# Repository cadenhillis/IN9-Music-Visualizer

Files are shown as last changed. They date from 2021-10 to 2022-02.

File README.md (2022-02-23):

# IN9-Music-Visualizer
Teensy 3.6  Based Music Visualizer utilizing the built-in audio library

11 IN9 Nixie tubes are driven thru low side BJT current sinks. Controllable thru the Teensy's PWM and powerful Audio Library.

The 12-150V boost supply is no laughing matter, by far the hardest to design -- as 11 IN9's can draw a peak of 20W. The medium power and high-voltage are quite a challenge for any electronics hobbiest.



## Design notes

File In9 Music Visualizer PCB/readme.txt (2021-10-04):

This top level KiCad project is the top-level schematic with the board.

The Power Board and Signal Board sub directorys are boards separated by their sections, as the power side works better with 2oz 4 layers and the signal side only needs 2 layers and 2oz is overkill

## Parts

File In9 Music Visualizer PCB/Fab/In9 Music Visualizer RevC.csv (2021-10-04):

Source: | E:\Projects\4.4 IN9 Music Visualizer RevC\In9 Music Visualizer RevC\In9 Music Visualizer RevC.sch
Date: | 8/29/2021 4:59:00 PM
Tool: | Eeschema (5.1.9)-1
Generator: | C:\Program Files\KiCad\bin\scripting\plugins/bom_csv_grouped_by_value.py
Component Count: | 98
Individual Components:
Item | Qty | Reference(s) | Value | LibPart | Footprint | Datasheet
 |  | C1 | 0.1uF | Device:C | Capacitor_SMD:C_0805_2012Metric_Pad1.18x1.45mm_HandSolder | 08055C104KAT4A
 |  | C2 | 620pF | Device:C | Capacitor_SMD:C_0805_2012Metric_Pad1.18x1.45mm_HandSolder | CC0805JRNPO9BN621
 |  | C3 | 0.1uF | Device:C | Capacitor_SMD:C_0805_2012Metric_Pad1.18x1.45mm_HandSolder | 08055C104KAT4A
 |  | C4 | 0.1uF | Device:C | Capacitor_SMD:C_0805_2012Metric_Pad1.18x1.45mm_HandSolder | 08055C104KAT4A
 |  | C5 | 100uF | Device:CP1 | Capacitor_THT:CP_Radial_D6.3mm_P2.50mm | ESY107M025AE3AA
 |  | C6 | 10uF | Device:C | Capacitor_SMD:C_0805_2012Metric_Pad1.18x1.45mm_HandSolder | GRM21BR61E106MA73L
 |  | C7 | 10uF | Device:C | Capacitor_SMD:C_0805_2012Metric_Pad1.18x1.45mm_HandSolder | GRM21BR61E106MA73L
 |  | C8 | 82uF | Device:CP1 | Capacitor_THT:CP_Radial_D18.0mm_P7.50mm | EEU-ED2E820S
 |  | C9 | 82uF | Device:CP1 | Capacitor_THT:CP_Radial_D18.0mm_P7.50mm | EEU-ED2E820S
 |  | C10 | 1uF | Device:C | Capacitor_SMD:C_2220_5650Metric_Pad1.97x5.40mm_HandSolder | C5750X7R2E105K230KA
 |  | C11 | 1uF | Device:C | Capacitor_SMD:C_2220_5650Metric_Pad1.97x5.40mm_HandSolder | C5750X7R2E105K230KA
 |  | C12 | 1uF | Device:C | Capacitor_SMD:C_2220_5650Metric_Pad1.97x5.40mm_HandSolder | C5750X7R2E105K230KA
 |  | C13 | 1uF | Device:C | Capacitor_SMD:C_2220_5650Metric_Pad1.97x5.40mm_HandSolder | C5750X7R2E105K230KA
 |  | C14 | 0.1uF | Device:C | Capacitor_SMD:C_0805_2012Metric_Pad1.18x1.45mm_HandSolder | 08055C104KAT4A
 |  | C15 | 0.16uF | Device:C | Capacitor_SMD:C_0805_2012Metric_Pad1.18x1.45mm_HandSolder | CL21B154KBFNNNG
 |  | C16 | 3.3nF | Device:C | Capacitor_SMD:C_0805_2012Metric_Pad1.18x1.45mm_HandSolder | 885012207119
 |  | C17 | 10nF | Device:C | Capacitor_SMD:C_0805_2012Metric_Pad1.18x1.45mm_HandSolder | 08055C103KAT2A
 |  | C18 | 0.1uF | Device:C | Capacitor_SMD:C_0805_2012Metric_Pad1.18x1.45mm_HandSolder | 08055C104KAT4A
 |  | C19 | 10uF | Device:C | Capacitor_SMD:C_0805_2012Metric_Pad1.18x1.45mm_HandSolder | GRM21BR61E106MA73L
 |  | C20 | 10uF | Device:C | Capacitor_SMD:C_0805_2012Metric_Pad1.18x1.45mm_HandSolder | GRM21BR61E106MA73L
 |  | C21 | 0.1uF | Device:C | Capacitor_SMD:C_0805_2012Metric_Pad1.18x1.45mm_HandSolder | 08055C104KAT4A
 |  | C22 | 22pF | Device:C | Capacitor_SMD:C_0805_2012Metric_Pad1.18x1.45mm_HandSolder | CL21C220JBANNNC
 |  | C23 | 22uF | Device:C | Capacitor_SMD:C_0805_2012Metric_Pad1.18x1.45mm_HandSolder | CL21A226MOCLRNC
 |  | C24 | 22uF | Device:C | Capacitor_SMD:C_0805_2012Metric_Pad1.18x1.45mm_HandSolder | CL21A226MOCLRNC
 |  | C25 | 4.7uF | Device:C | Capacitor_SMD:C_0805_2012Metric_Pad1.18x1.45mm_HandSolder | CL21A475KPFNNNE
 |  | C26 | 4.7uF | Device:C | Capacitor_SMD:C_0805_2012Metric_Pad1.18x1.45mm_HandSolder | CL21A475KPFNNNE
 |  | C27 | 4.7uF | Device:C | Capacitor_SMD:C_0805_2012Metric_Pad1.18x1.45mm_HandSolder | CL21A475KPFNNNE
 |  | C28 | 4.7uF | Device:C | Capacitor_SMD:C_0805_2012Metric_Pad1.18x1.45mm_HandSolder | CL21A475KPFNNNE
 |  | C29 | 4.7uF | Device:C | Capacitor_SMD:C_0805_2012Metric_Pad1.18x1.45mm_HandSolder | CL21A475KPFNNNE
 |  | C30 | 4.7uF | Device:C | Capacitor_SMD:C_0805_2012Metric_Pad1.18x1.45mm_HandSolder | CL21A475KPFNNNE
 |  | C31 | 4.7uF | Device:C | Capacitor_SMD:C_0805_2012Metric_Pad1.18x1.45mm_HandSolder | CL21A475KPFNNNE
 |  | C32 | 4.7uF | Device:C | Capacitor_SMD:C_0805_2012Metric_Pad1.18x1.45mm_HandSolder | CL21A475KPFNNNE
 |  | C33 | 4.7uF | Device:C | Capacitor_SMD:C_0805_2012Metric_Pad1.18x1.45mm_HandSolder | CL21A475KPFNNNE
 |  | C34 | 4.7uF | Device:C | Capacitor_SMD:C_0805_2012Metric_Pad1.18x1.45mm_HandSolder | CL21A475KPFNNNE
 |  | C35 | 4.7uF | Device:C | Capacitor_SMD:C_0805_2012Metric_Pad1.18x1.45mm_HandSolder | CL21A475KPFNNNE
 |  | D1 | MUR860J | Device:D | Diode_SMD:D_SMC_Handsoldering | MUR860J
 |  | HS1 | V6560W | Mechanical:Heatsink | My_Library:V6560W | V6560W
 |  | J1 | PWR_IN | Connector_Generic:Conn_01x02 | My_Library:640456-2 | 640456-2
 |  | J2 | PWR_IN | Connector_Generic:Conn_01x02 | My_Library:640456-2 | 640456-2
 |  | J3 | MIC_INPUT | Connector_Generic:Conn_01x03 | My_Library:640456-3 | 640456-3
 |  | J4 | IN9_MOUNTING_BOARD | Connector_Generic:Conn_01x12 | Connector_PinHeader_2.54mm:PinHeader_2x06_P2.54mm_Vertical | BHR-12-VUA
 |  | L1 | 330uH | Device:L | My_Library:L_Murata_6000B | 60B334C
 |  | L2 | 4.7uH | Device:L | Inductor_SMD:L_Bourns_SRN6045TA | SRN6045-4R7Y
 |  | MCU1 | Teensy 3.6 | Connector_Generic:Conn_02x24_Counter_Clockwise | My_Library:Teensy3.6 | ~
 |  | Q1 | DMN6140L-13 | Device:Q_NMOS_GSD | Package_TO_SOT_SMD:SOT-23_Handsoldering | DMN6140L-13
 |  | Q2 | STF13NM60N | Device:Q_NMOS_GDS | Package_TO_SOT_THT:TO-220-3_Vertical | STF13NM60N
 |  | Q3 | FZT857TA | Device:Q_NPN_BCE | Package_TO_SOT_SMD:SOT-223-3_TabPin2 | FZT857TA
 |  | Q4 | FZT857TA | Device:Q_NPN_BCE | Package_TO_SOT_SMD:SOT-223-3_TabPin2 | FZT857TA
 |  | Q5 | FZT857TA | Device:Q_NPN_BCE | Package_TO_SOT_SMD:SOT-223-3_TabPin2 | FZT857TA
 |  | Q6 | FZT857TA | Device:Q_NPN_BCE | Package_TO_SOT_SMD:SOT-223-3_TabPin2 | FZT857TA
 |  | Q7 | FZT857TA | Device:Q_NPN_BCE | Package_TO_SOT_SMD:SOT-223-3_TabPin2 | FZT857TA
 |  | Q8 | FZT857TA | Device:Q_NPN_BCE | Package_TO_SOT_SMD:SOT-223-3_TabPin2 | FZT857TA
 |  | Q9 | FZT857TA | Device:Q_NPN_BCE | Package_TO_SOT_SMD:SOT-223-3_TabPin2 | FZT857TA
 |  | Q10 | FZT857TA | Device:Q_NPN_BCE | Package_TO_SOT_SMD:SOT-223-3_TabPin2 | FZT857TA
 |  | Q11 | FZT857TA | Device:Q_NPN_BCE | Package_TO_SOT_SMD:SOT-223-3_TabPin2 | FZT857TA
 |  | Q12 | FZT857TA | Device:Q_NPN_BCE | Package_TO_SOT_SMD:SOT-223-3_TabPin2 | FZT857TA
 |  | Q13 | FZT857TA | Device:Q_NPN_BCE | Package_TO_SOT_SMD:SOT-223-3_TabPin2 | FZT857TA
 |  | R1 | 10k | Device:R_US | Resistor_SMD:R_0805_2012Metric_Pad1.20x1.40mm_HandSolder | RNCP0805FTD10K0
 |  | R2 | 69.8k | Device:R_US | Resistor_SMD:R_0805_2012Metric_Pad1.20x1.40mm_HandSolder | RC0805FR-0769K8L
 |  | R3 | 330 | Device:R_US | Resistor_SMD:R_0805_2012Metric_Pad1.20x1.40mm_HandSolder | CRGCQ0805F330R
 |  | R4 | 20k | Device:R_US | Resistor_SMD:R_0805_2012Metric_Pad1.20x1.40mm_HandSolder | CRG0805F20K
 |  | R5 | 10k | Device:R_US | Resistor_SMD:R_0805_2012Metric_Pad1.20x1.40mm_HandSolder | RNCP0805FTD10K0
 |  | R6 | 10k | Device:R_US | Resistor_SMD:R_0805_2012Metric_Pad1.20x1.40mm_HandSolder | RNCP0805FTD10K0
 |  | R7 | 20 | Device:R_US | Resistor_SMD:R_0805_2012Metric_Pad1.20x1.40mm_HandSolder | RNCP0805FTD20R0
 |  | R8 | 180k | Device:R_US | Resistor_SMD:R_0805_2012Metric_Pad1.20x1.40mm_HandSolder | RMCF0805FT180K
 |  | R9 | 1M | Device:R_US | Resistor_SMD:R_0805_2012Metric_Pad1.20x1.40mm_HandSolder | RK73B2ATTD105J
 |  | R10 | 0.0 | Device:R_US | Resistor_SMD:R_0805_2012Metric_Pad1.20x1.40mm_HandSolder | RC0805JR-070RL
 |  | R11 | 1.6k | Device:R_US | Resistor_SMD:R_0805_2012Metric_Pad1.20x1.40mm_HandSolder | RC0805FR-071K6L
 |  | R12 | 49.9k | Device:R_US | Resistor_SMD:R_0805_2012Metric_Pad1.20x1.40mm_HandSolder | RNCP0805FTD49K9
 |  | R13 | 39m | Device:R_US | Resistor_SMD:R_1206_3216Metric_Pad1.30x1.75mm_HandSolder | ERJ-8CWJR039V
 |  | R14 | 49.9k | Device:R_US | Resistor_SMD:R_0805_2012Metric_Pad1.20x1.40mm_HandSolder | RNCP0805FTD49K9
 |  | R15 | 52.3k | Device:R_US | Resistor_SMD:R_0805_2012Metric_Pad1.20x1.40mm_HandSolder | RC0805FR-0752K3L
 |  | R16 | 10k | Device:R_US | Resistor_SMD:R_0805_2012Metric_Pad1.20x1.40mm_HandSolder | RNCP0805FTD10K0
 |  | R17 | 2.2k | Device:R_US | Resistor_SMD:R_0805_2012Metric_Pad1.20x1.40mm_HandSolder | RR1220P-222-D
 |  | R18 | 2.2k | Device:R_US | Resistor_SMD:R_0805_2012Metric_Pad1.20x1.40mm_HandSolder | RR1220P-222-D
 |  | R19 | 2.2k | Device:R_US | Resistor_SMD:R_0805_2012Metric_Pad1.20x1.40mm_HandSolder | RR1220P-222-D
 |  | R20 | 2.2k | Device:R_US | Resistor_SMD:R_0805_2012Metric_Pad1.20x1.40mm_HandSolder | RR1220P-222-D
 |  | R21 | 2.2k | Device:R_US | Resistor_SMD:R_0805_2012Metric_Pad1.20x1.40mm_HandSolder | RR1220P-222-D
 |  | R22 | 2.2k | Device:R_US | Resistor_SMD:R_0805_2012Metric_Pad1.20x1.40mm_HandSolder | RR1220P-222-D
 |  | R23 | 180 | Device:R_US | Resistor_SMD:R_0805_2012Metric_Pad1.20x1.40mm_HandSolder | CRG0805F180R
 |  | R24 | 180 | Device:R_US | Resistor_SMD:R_0805_2012Metric_Pad1.20x1.40mm_HandSolder | CRG0805F180R
 |  | R25 | 180 | Device:R_US | Resistor_SMD:R_0805_2012Metric_Pad1.20x1.40mm_HandSolder | CRG0805F180R
 |  | R26 | 180 | Device:R_US | Resistor_SMD:R_0805_2012Metric_Pad1.20x1.40mm_HandSolder | CRG0805F180R
 |  | R27 | 180 | Device:R_US | Resistor_SMD:R_0805_2012Metric_Pad1.20x1.40mm_HandSolder | CRG0805F180R
 |  | R28 | 180 | Device:R_US | Resistor_SMD:R_0805_2012Metric_Pad1.20x1.40mm_HandSolder | CRG0805F180R
 |  | R29 | 2.2k | Device:R_US | Resistor_SMD:R_0805_2012Metric_Pad1.20x1.40mm_HandSolder | RR1220P-222-D
 |  | R30 | 2.2k | Device:R_US | Resistor_SMD:R_0805_2012Metric_Pad1.20x1.40mm_HandSolder | RR1220P-222-D
 |  | R31 | 2.2k | Device:R_US | Resistor_SMD:R_0805_2012Metric_Pad1.20x1.40mm_HandSolder | RR1220P-222-D
 |  | R32 | 2.2k | Device:R_US | Resistor_SMD:R_0805_2012Metric_Pad1.20x1.40mm_HandSolder | RR1220P-222-D
 |  | R33 | 2.2k | Device:R_US | Resistor_SMD:R_0805_2012Metric_Pad1.20x1.40mm_HandSolder | RR1220P-222-D
 |  | R34 | 180 | Device:R_US | Resistor_SMD:R_0805_2012Metric_Pad1.20x1.40mm_HandSolder | CRG0805F180R
 |  | R35 | 180 | Device:R_US | Resistor_SMD:R_0805_2012Metric_Pad1.20x1.40mm_HandSolder | CRG0805F180R
 |  | R36 | 180 | Device:R_US | Resistor_SMD:R_0805_2012Metric_Pad1.20x1.40mm_HandSolder | CRG0805F180R
 |  | R37 | 180 | Device:R_US | Resistor_SMD:R_0805_2012Metric_Pad1.20x1.40mm_HandSolder | CRG0805F180R
 |  | R38 | 180 | Device:R_US | Resistor_SMD:R_0805_2012Metric_Pad1.20x1.40mm_HandSolder | CRG0805F180R
 |  | U1 | LMV358 | Amplifier_Operational:LMV358 | Package_SO:SOIC-8_3.9x4.9mm_P1.27mm | LMV358ID
 |  | U2 | LM3478 | My_Library:LM3478 | Package_SO:SO-8_3.9x4.9mm_P1.27mm | LM3478MAX/NOPB
 |  | U3 | TPS352207 | My_Library:TPS352207 | Package_TO_SOT_SMD:SOT-563 | TPS352207
Collated Components:
Item | Qty | Reference(s) | Value | LibPart | Footprint | Datasheet
1 | 6 | C1, C3, C4, C14, C18, C21 | 0.1uF | Device:C | Capacitor_SMD:C_0805_2012Metric_Pad1.18x1.45mm_HandSolder | 08055C104KAT4A
2 | 1 | C2 | 620pF | Device:C | Capacitor_SMD:C_0805_2012Metric_Pad1.18x1.45mm_HandSolder | CC0805JRNPO9BN621
3 | 1 | C5 | 100uF | Device:CP1 | Capacitor_THT:CP_Radial_D6.3mm_P2.50mm | ESY107M025AE3AA
4 | 4 | C6, C7, C19, C20 | 10uF | Device:C | Capacitor_SMD:C_0805_2012Metric_Pad1.18x1.45mm_HandSolder | GRM21BR61E106MA73L
5 | 2 | C8, C9 | 82uF | Device:CP1 | Capacitor_THT:CP_Radial_D18.0mm_P7.50mm | EEU-ED2E820S
6 | 4 | C10, C11, C12, C13 | 1uF | Device:C | Capacitor_SMD:C_2220_5650Metric_Pad1.97x5.40mm_HandSolder | C5750X7R2E105K230KA
7 | 1 | C15 | 0.16uF | Device:C | Capacitor_SMD:C_0805_2012Metric_Pad1.18x1.45mm_HandSolder | CL21B154KBFNNNG
8 | 1 | C16 | 3.3nF | Device:C | Capacitor_SMD:C_0805_2012Metric_Pad1.18x1.45mm_HandSolder | 885012207119
9 | 1 | C17 | 10nF | Device:C | Capacitor_SMD:C_0805_2012Metric_Pad1.18x1.45mm_HandSolder | 08055C103KAT2A
10 | 1 | C22 | 22pF | Device:C | Capacitor_SMD:C_0805_2012Metric_Pad1.18x1.45mm_HandSolder | CL21C220JBANNNC
11 | 2 | C23, C24 | 22uF | Device:C | Capacitor_SMD:C_0805_2012Metric_Pad1.18x1.45mm_HandSolder | CL21A226MOCLRNC
12 | 11 | C25, C26, C27, C28, C29, C30, C31, C32, C33, C34, C35 | 4.7uF | Device:C | Capacitor_SMD:C_0805_2012Metric_Pad1.18x1.45mm_HandSolder | CL21A475KPFNNNE
13 | 1 | D1 | MUR860J | Device:D | Diode_SMD:D_SMC_Handsoldering | MUR860J
14 | 1 | HS1 | V6560W | Mechanical:Heatsink | My_Library:V6560W | V6560W
15 | 2 | J1, J2 | PWR_IN | Connector_Generic:Conn_01x02 | My_Library:640456-2 | 640456-2
16 | 1 | J3 | MIC_INPUT | Connector_Generic:Conn_01x03 | My_Library:640456-3 | 640456-3
17 | 1 | J4 | IN9_MOUNTING_BOARD | Connector_Generic:Conn_01x12 | Connector_PinHeader_2.54mm:PinHeader_2x06_P2.54mm_Vertical | BHR-12-VUA
18 | 1 | L1 | 330uH | Device:L | My_Library:L_Murata_6000B | 60B334C
19 | 1 | L2 | 4.7uH | Device:L | Inductor_SMD:L_Bourns_SRN6045TA | SRN6045-4R7Y
20 | 1 | MCU1 | Teensy 3.6 | Connector_Generic:Conn_02x24_Counter_Clockwise | My_Library:Teensy3.6 | ~
21 | 1 | Q1 | DMN6140L-13 | Device:Q_NMOS_GSD | Package_TO_SOT_SMD:SOT-23_Handsoldering | DMN6140L-13
22 | 1 | Q2 | STF13NM60N | Device:Q_NMOS_GDS | Package_TO_SOT_THT:TO-220-3_Vertical | STF13NM60N
23 | 11 | Q3, Q4, Q5, Q6, Q7, Q8, Q9, Q10, Q11, Q12, Q13 | FZT857TA | Device:Q_NPN_BCE | Package_TO_SOT_SMD:SOT-223-3_TabPin2 | FZT857TA
24 | 4 | R1, R5, R6, R16 | 10k | Device:R_US | Resistor_SMD:R_0805_2012Metric_Pad1.20x1.40mm_HandSolder | RNCP0805FTD10K0
25 | 1 | R2 | 69.8k | Device:R_US | Resistor_SMD:R_0805_2012Metric_Pad1.20x1.40mm_HandSolder | RC0805FR-0769K8L
26 | 1 | R3 | 330 | Device:R_US | Resistor_SMD:R_0805_2012Metric_Pad1.20x1.40mm_HandSolder | CRGCQ0805F330R
27 | 1 | R4 | 20k | Device:R_US | Resistor_SMD:R_0805_2012Metric_Pad1.20x1.40mm_HandSolder | CRG0805F20K
28 | 1 | R7 | 20 | Device:R_US | Resistor_SMD:R_0805_2012Metric_Pad1.20x1.40mm_HandSolder | RNCP0805FTD20R0
29 | 1 | R8 | 180k | Device:R_US | Resistor_SMD:R_0805_2012Metric_Pad1.20x1.40mm_HandSolder | RMCF0805FT180K
30 | 1 | R9 | 1M | Device:R_US | Resistor_SMD:R_0805_2012Metric_Pad1.20x1.40mm_HandSolder | RK73B2ATTD105J
31 | 1 | R10 | 0.0 | Device:R_US | Resistor_SMD:R_0805_2012Metric_Pad1.20x1.40mm_HandSolder | RC0805JR-070RL
32 | 1 | R11 | 1.6k | Device:R_US | Resistor_SMD:R_0805_2012Metric_Pad1.20x1.40mm_HandSolder | RC0805FR-071K6L
33 | 2 | R12, R14 | 49.9k | Device:R_US | Resistor_SMD:R_0805_2012Metric_Pad1.20x1.40mm_HandSolder | RNCP0805FTD49K9
34 | 1 | R13 | 39m | Device:R_US | Resistor_SMD:R_1206_3216Metric_Pad1.30x1.75mm_HandSolder | ERJ-8CWJR039V
35 | 1 | R15 | 52.3k | Device:R_US | Resistor_SMD:R_0805_2012Metric_Pad1.20x1.40mm_HandSolder | RC0805FR-0752K3L
36 | 11 | R17, R18, R19, R20, R21, R22, R29, R30, R31, R32, R33 | 2.2k | Device:R_US | Resistor_SMD:R_0805_2012Metric_Pad1.20x1.40mm_HandSolder | RR1220P-222-D
37 | 11 | R23, R24, R25, R26, R27, R28, R34, R35, R36, R37, R38 | 180 | Device:R_US | Resistor_SMD:R_0805_2012Metric_Pad1.20x1.40mm_HandSolder | CRG0805F180R
38 | 1 | U1 | LMV358 | Amplifier_Operational:LMV358 | Package_SO:SOIC-8_3.9x4.9mm_P1.27mm | LMV358ID
39 | 1 | U2 | LM3478 | My_Library:LM3478 | Package_SO:SO-8_3.9x4.9mm_P1.27mm | LM3478MAX/NOPB
40 | 1 | U3 | TPS352207 | My_Library:TPS352207 | Package_TO_SOT_SMD:SOT-563 | TPS352207

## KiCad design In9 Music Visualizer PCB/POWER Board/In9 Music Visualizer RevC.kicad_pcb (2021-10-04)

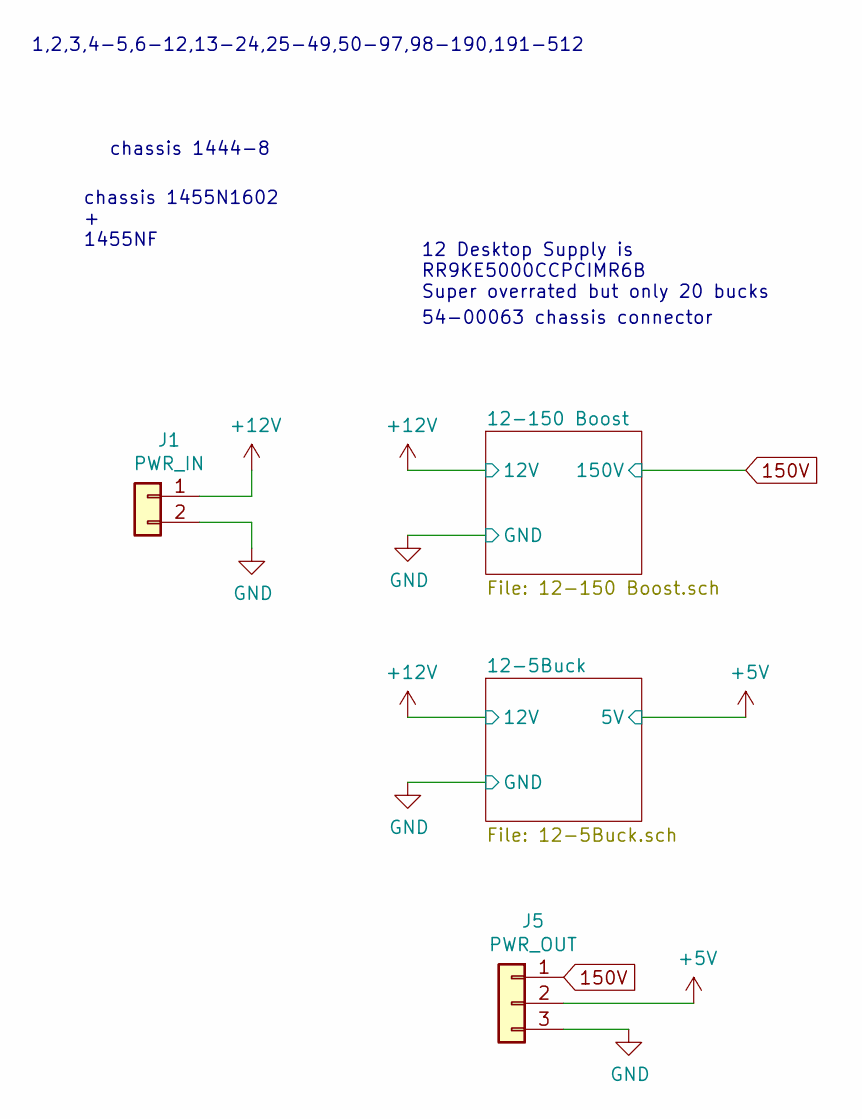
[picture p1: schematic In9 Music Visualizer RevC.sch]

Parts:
J1: PWR_IN; 640456-2
J5: PWR_OUT; 640456-3

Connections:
150V: J5.1; also elsewhere on the board
+5V: J5.2; also elsewhere on the board
+12V: J1.1; also elsewhere on the board
GND: J1.2, J5.3; also elsewhere on the board

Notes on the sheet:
chassis 1455N1602 + 1455NF
chassis 1444-8
54-00063 chassis connector
1,2,3,4-5,6-12,13-24,25-49,50-97,98-190,191-512
12 Desktop Supply is RR9KE5000CCPCIMR6B Super overrated but only 20 bucks

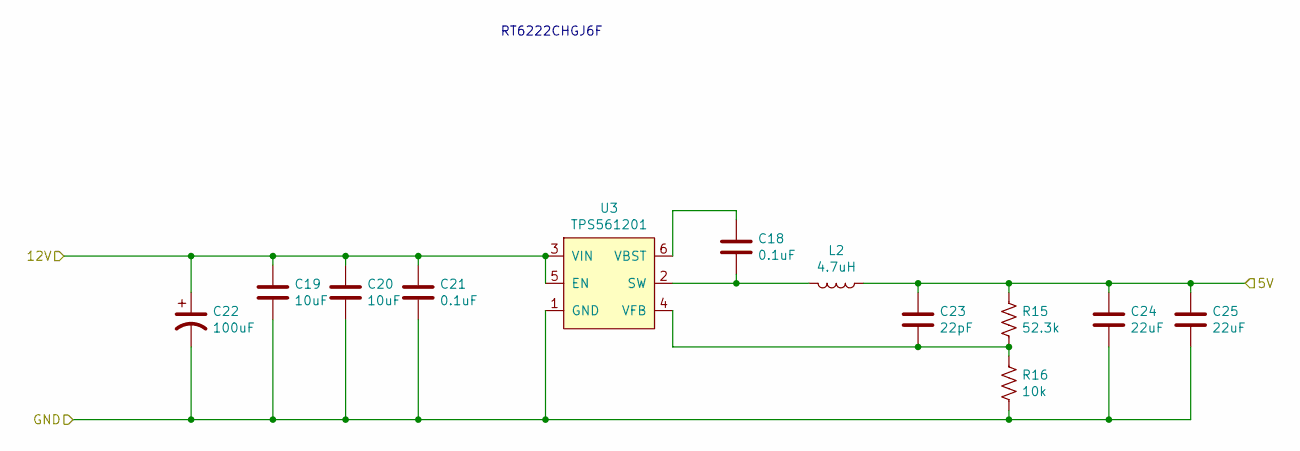
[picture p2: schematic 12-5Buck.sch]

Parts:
C18, C21: 0.1uF; C_0805_2012Metric_Pad1.18x1.45mm_HandSolder
C19, C20: 10uF; C_0805_2012Metric_Pad1.18x1.45mm_HandSolder
C22: 100uF; CP_Radial_D6.3mm_P2.50mm
C23: 22pF; C_0805_2012Metric_Pad1.18x1.45mm_HandSolder
C24, C25: 22uF; C_0805_2012Metric_Pad1.18x1.45mm_HandSolder
L2: 4.7uH; L_Bourns_SRN6045TA
R15: 52.3k; R_0805_2012Metric_Pad1.20x1.40mm_HandSolder
R16: 10k; R_0805_2012Metric_Pad1.20x1.40mm_HandSolder
U3: TPS561201; SOT-23-6

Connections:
+5V: C23.1, C24.1, C25.1, L2.1, R15.1; also elsewhere on the board
+12V: C19.1, C20.1, C21.1, C22.1, U3.3 (VIN), U3.5 (EN); also elsewhere on the board
GND: C19.2, C20.2, C21.2, C22.2, C24.2, C25.2, R16.2, U3.1 (GND); also elsewhere on the board
unnamed: C18.1, U3.6 (VBST)
unnamed: C18.2, L2.2, U3.2 (SW)
unnamed: C23.2, R15.2, R16.1, U3.4 (VFB)

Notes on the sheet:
RT6222CHGJ6F

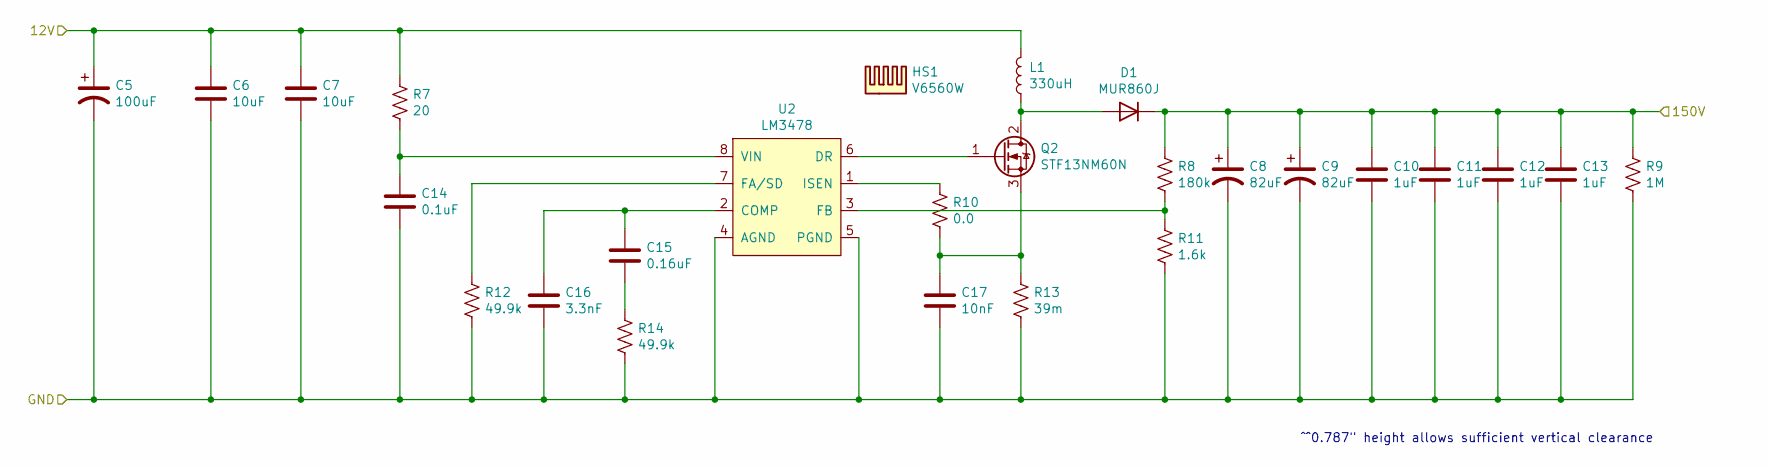
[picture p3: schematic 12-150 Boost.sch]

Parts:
C5: 100uF; CP_Radial_D6.3mm_P2.50mm
C6, C7: 10uF; C_0805_2012Metric_Pad1.18x1.45mm_HandSolder
C8, C9: 82uF; CP_Radial_D18.0mm_P7.50mm
C10, C11, C12, C13: 1uF; C_2220_5650Metric_Pad1.97x5.40mm_HandSolder
C14: 0.1uF; C_0805_2012Metric_Pad1.18x1.45mm_HandSolder
C15: 0.16uF; C_0805_2012Metric_Pad1.18x1.45mm_HandSolder
C16: 3.3nF; C_0805_2012Metric_Pad1.18x1.45mm_HandSolder
C17: 10nF; C_0805_2012Metric_Pad1.18x1.45mm_HandSolder
D1: MUR860J; D_SMC_Handsoldering
HS1: V6560W
L1: 330uH; L_Murata_6000B
Q2: STF13NM60N; TO-220-3_Vertical
R7: 20; R_0805_2012Metric_Pad1.20x1.40mm_HandSolder
R8: 180k; R_0805_2012Metric_Pad1.20x1.40mm_HandSolder
R9: 1M; R_0805_2012Metric_Pad1.20x1.40mm_HandSolder
R10: 0.0; R_0805_2012Metric_Pad1.20x1.40mm_HandSolder
R11: 1.6k; R_0805_2012Metric_Pad1.20x1.40mm_HandSolder
R12, R14: 49.9k; R_0805_2012Metric_Pad1.20x1.40mm_HandSolder
R13: 39m; R_1206_3216Metric_Pad1.30x1.75mm_HandSolder
U2: LM3478; SO-8_3.9x4.9mm_P1.27mm

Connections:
150V: C8.1, C9.1, C10.1, C11.1, C12.1, C13.1, D1.1 (K), R8.1, R9.1; also elsewhere on the board
+12V: C5.1, C6.1, C7.1, L1.2, R7.1; also elsewhere on the board
GND: C5.2, C6.2, C7.2, C8.2, C9.2, C10.2, C11.2, C12.2, C13.2, C14.2, C16.2, C17.2, R9.2, R11.2, R12.2, R13.2, R14.2, U2.4 (AGND), U2.5 (PGND); also elsewhere on the board
unnamed: C14.1, R7.2, U2.8 (VIN)
unnamed: C15.1, C16.1, U2.2 (COMP)
unnamed: C15.2, R14.1
unnamed: C17.1, Q2.3 (S), R10.1, R13.1
unnamed: D1.2 (A), L1.1, Q2.2 (D)
unnamed: Q2.1 (G), U2.6 (DR)
unnamed: R10.2, U2.1 (ISEN)
unnamed: R8.2, R11.1, U2.3 (FB)
unnamed: R12.1, U2.7 (FA/SD)

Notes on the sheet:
^^0.787" height allows sufficient vertical clearance

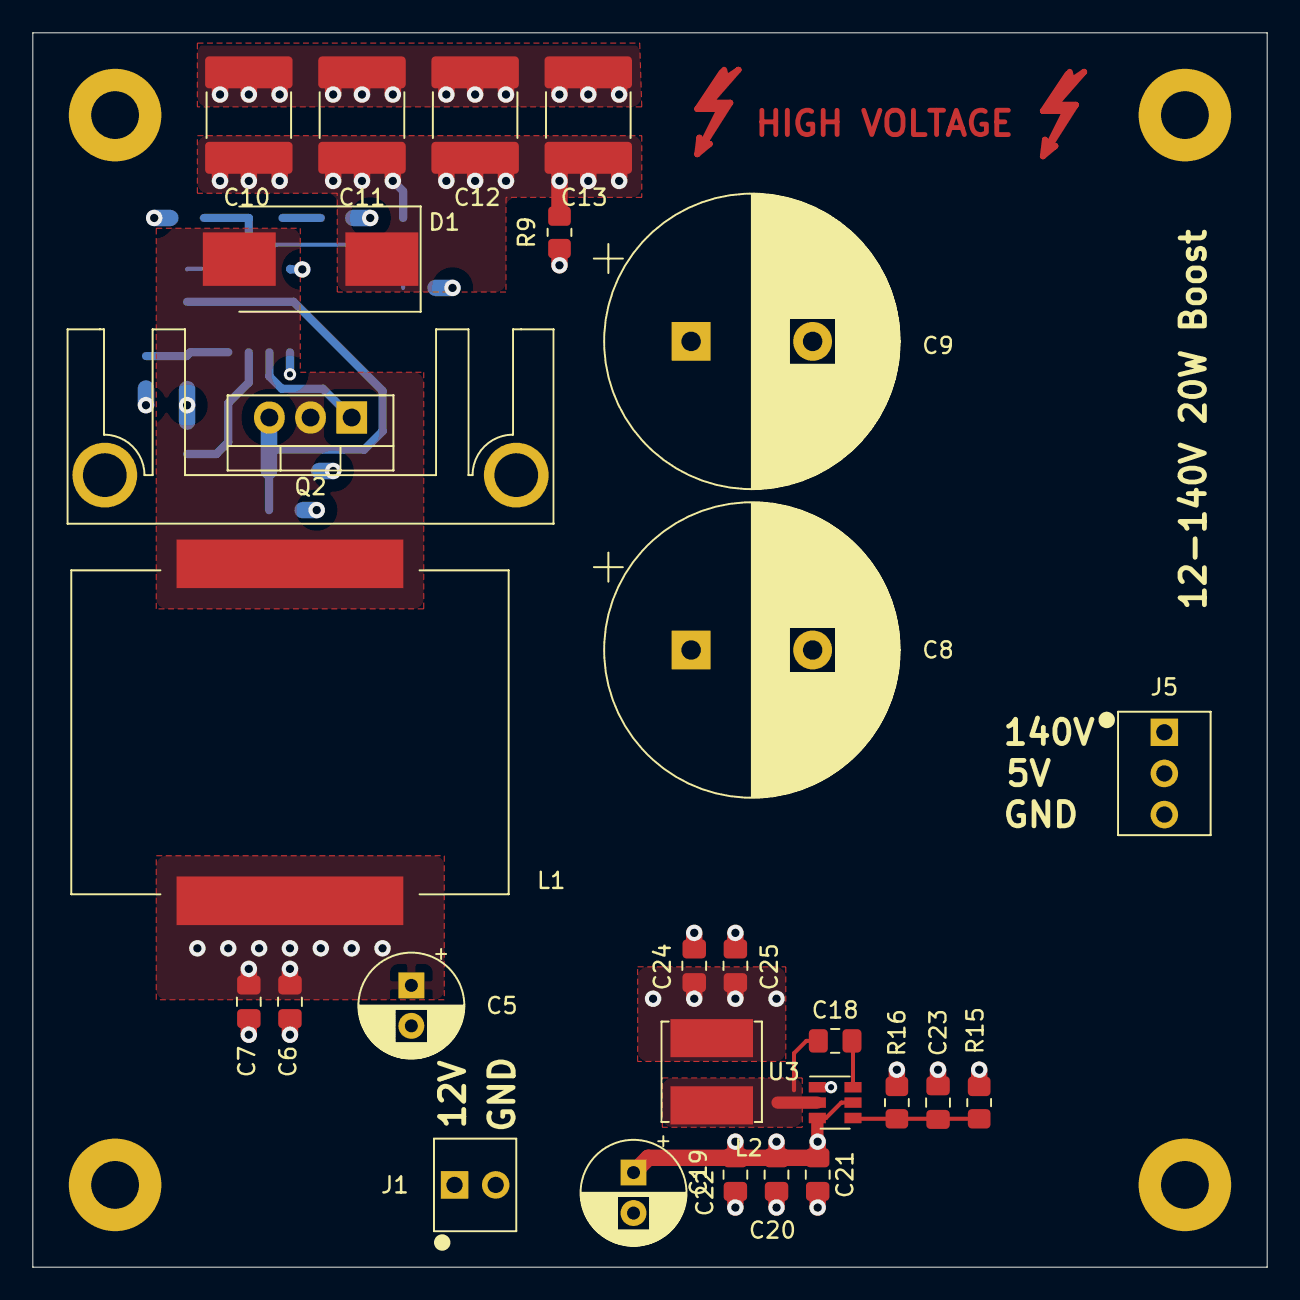
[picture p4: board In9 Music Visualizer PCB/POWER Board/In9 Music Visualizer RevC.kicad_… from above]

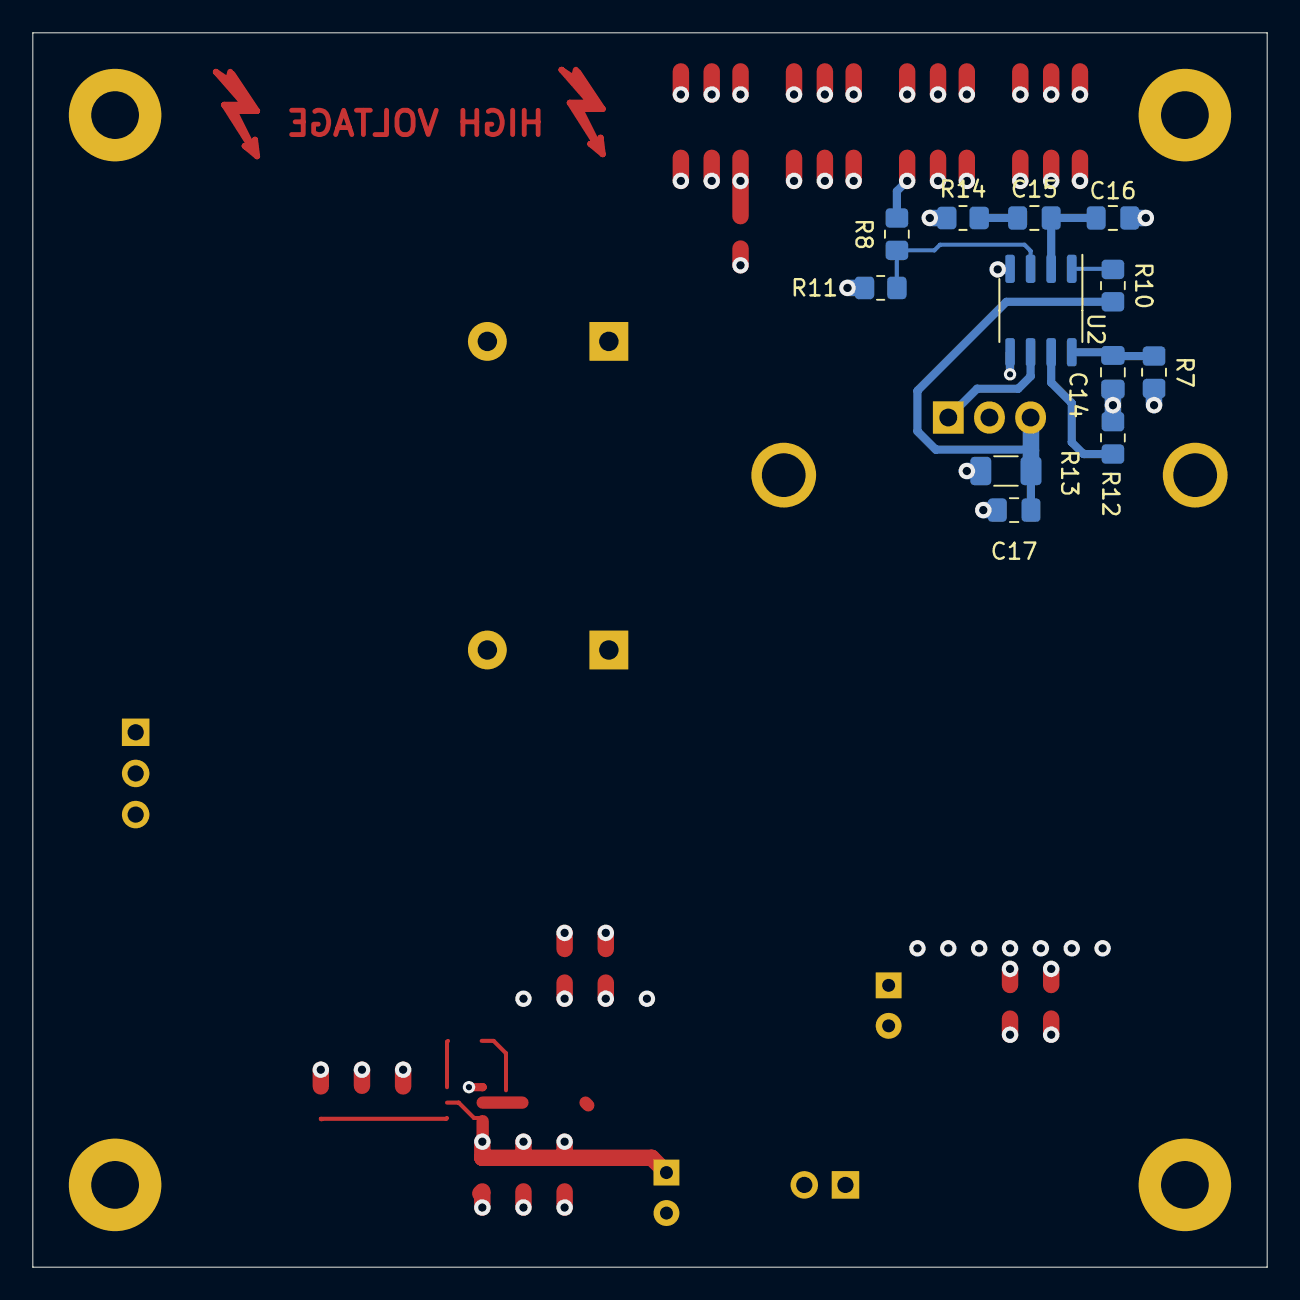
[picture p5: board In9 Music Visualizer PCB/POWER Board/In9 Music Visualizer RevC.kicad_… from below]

Board: 4 copper layers, 76.2 x 76.2 mm, 40 parts (12 on the bottom side), 16 nets.

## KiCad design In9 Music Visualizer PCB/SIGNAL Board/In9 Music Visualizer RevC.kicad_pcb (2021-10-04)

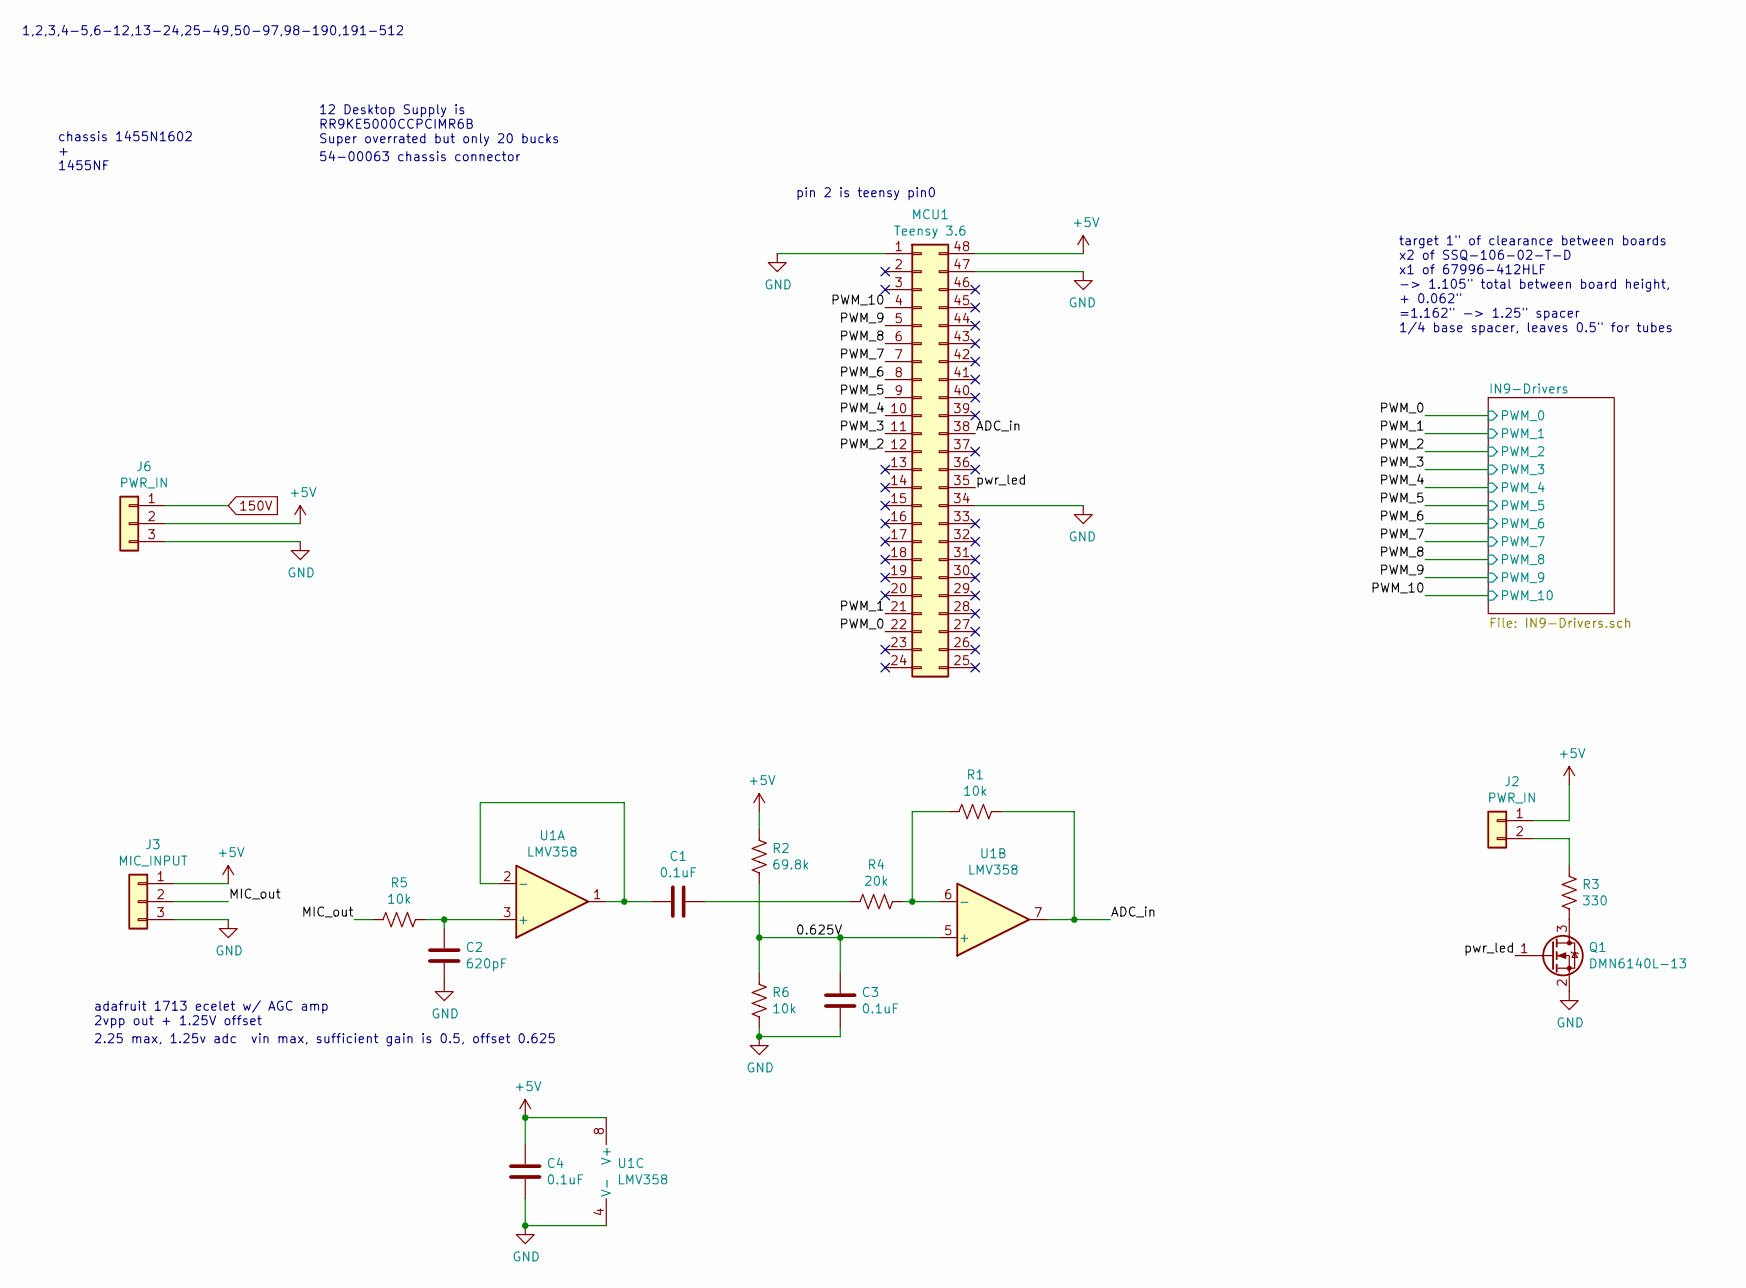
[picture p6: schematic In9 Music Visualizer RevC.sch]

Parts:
C1, C3, C4: 0.1uF; C_0805_2012Metric_Pad1.18x1.45mm_HandSolder
C2: 620pF; C_0805_2012Metric_Pad1.18x1.45mm_HandSolder
J2: PWR_IN; 640456-2
J3: MIC_INPUT; 640456-3
J6: PWR_IN; 640456-3
MCU1: Teensy 3.6; Teensy3.6
Q1: DMN6140L-13; SOT-23_Handsoldering
R1, R5, R6: 10k; R_0805_2012Metric_Pad1.20x1.40mm_HandSolder
R2: 69.8k; R_0805_2012Metric_Pad1.20x1.40mm_HandSolder
R3: 330; R_0805_2012Metric_Pad1.20x1.40mm_HandSolder
R4: 20k; R_0805_2012Metric_Pad1.20x1.40mm_HandSolder
U1: LMV358; SOIC-8_3.9x4.9mm_P1.27mm

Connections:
150V: J6.1; also elsewhere on the board
+5V: C4.1, J2.1, J3.1, J6.2, MCU1.48, R2.1, U1.8 (V+)
/0.625V: C3.1, R2.2, R6.1, U1.5 (+)
/ADC_in: MCU1.38, R1.1, U1.7
/MIC_out: J3.2, R5.2
/PWM_0: MCU1.22; also elsewhere on the board
/PWM_1: MCU1.21; also elsewhere on the board
/PWM_2: MCU1.12; also elsewhere on the board
/PWM_3: MCU1.11; also elsewhere on the board
/PWM_4: MCU1.10; also elsewhere on the board
/PWM_5: MCU1.9; also elsewhere on the board
/PWM_6: MCU1.8; also elsewhere on the board
/PWM_7: MCU1.7; also elsewhere on the board
/PWM_8: MCU1.6; also elsewhere on the board
/PWM_9: MCU1.5; also elsewhere on the board
/PWM_10: MCU1.4; also elsewhere on the board
/pwr_led: MCU1.35, Q1.1 (G)
GND: C2.2, C3.2, C4.2, J3.3, J6.3, MCU1.1, MCU1.34, MCU1.47, Q1.2 (S), R6.2, U1.4 (V-); also elsewhere on the board
unnamed: C1.1, R4.2
unnamed: C1.2, U1.1, U1.2 (-)
unnamed: C2.1, R5.1, U1.3 (+)
unnamed: J2.2, R3.1
unnamed: Q1.3 (D), R3.2
unnamed: R1.2, R4.1, U1.6 (-)

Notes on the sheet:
12 Desktop Supply is RR9KE5000CCPCIMR6B Super overrated but only 20 bucks
adafruit 1713 ecelet w/ AGC amp 2vpp out + 1.25V offset
1,2,3,4-5,6-12,13-24,25-49,50-97,98-190,191-512
2.25 max, 1.25v adc vin max, sufficient gain is 0.5, offset 0.625
target 1" of clearance between boards x2 of SSQ-106-02-T-D x1 of 67996-412HLF -> 1.105" total between board height, + 0.062" =1.162" -> 1.25" spacer 1/4 base spacer, leaves 0.5" for tubes
54-00063 chassis connector
pin 2 is teensy pin0
chassis 1455N1602 + 1455NF

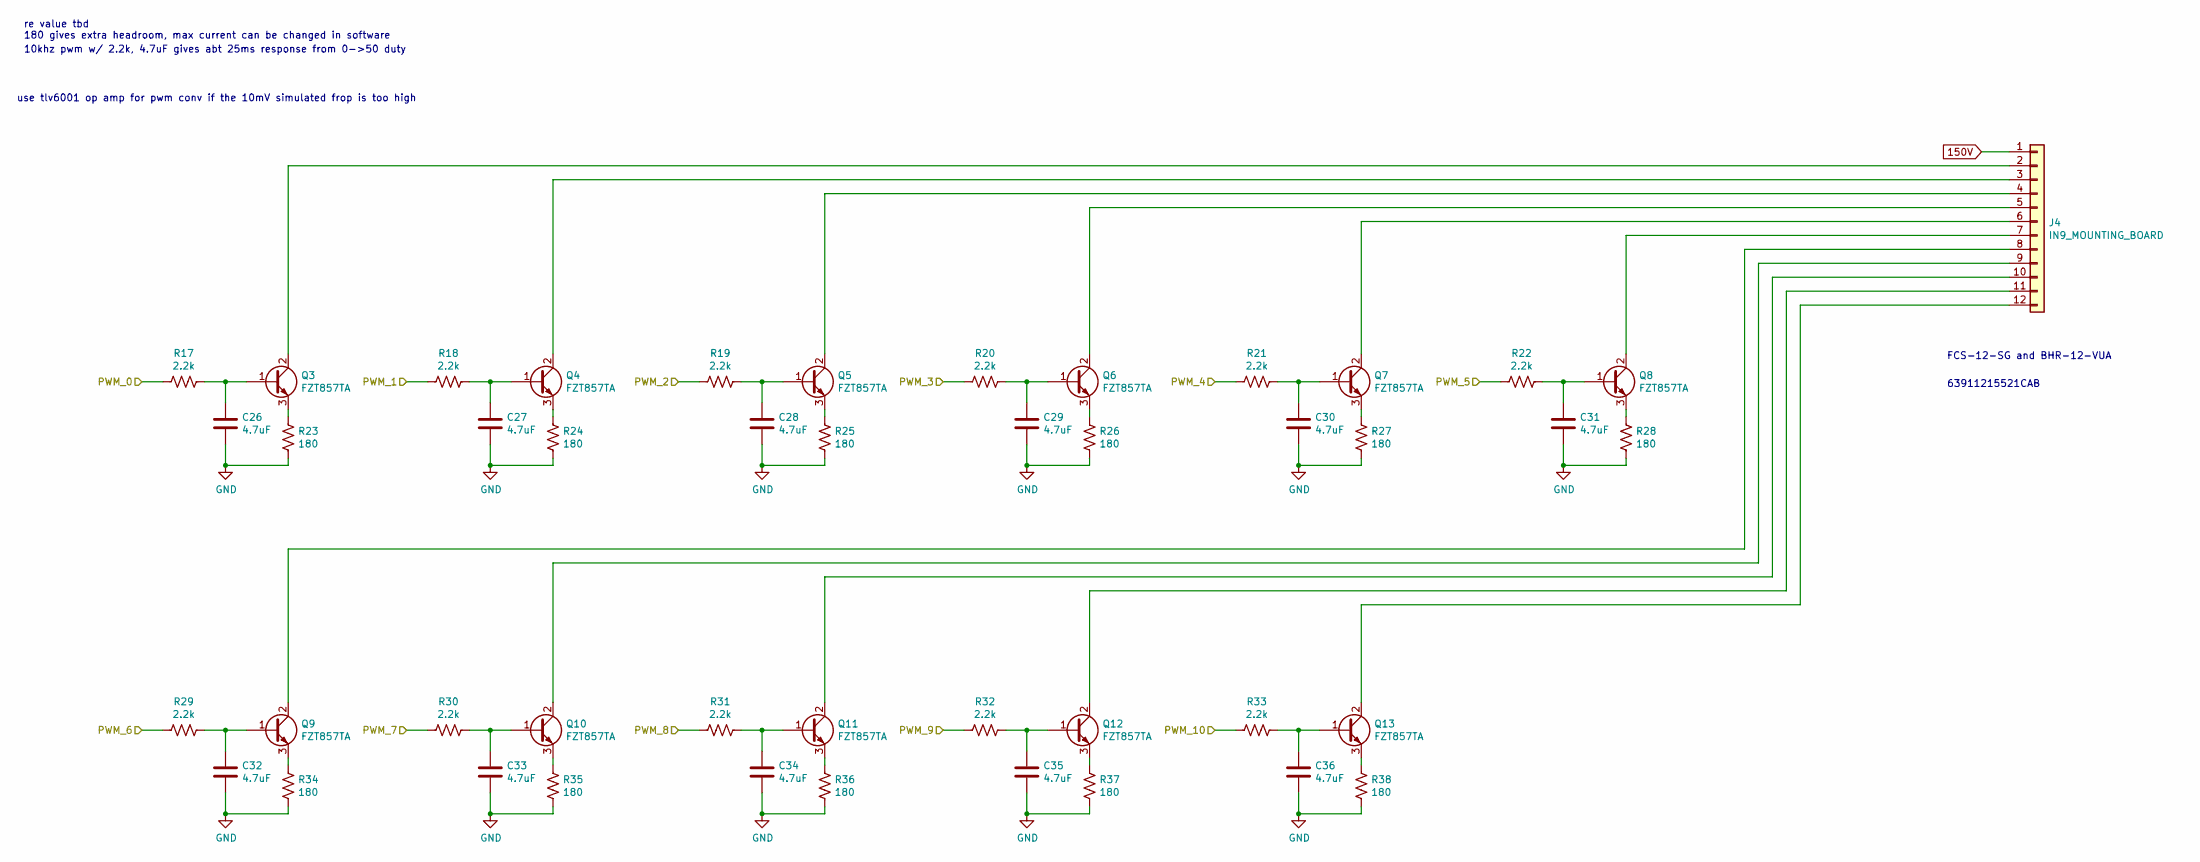
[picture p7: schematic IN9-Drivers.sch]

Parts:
C26, C27, C28, C29, C30, C31, C32, C33, C34, C35, C36: 4.7uF; C_0805_2012Metric_Pad1.18x1.45mm_HandSolder
J4: IN9_MOUNTING_BOARD; PinHeader_2x06_P2.54mm_Vertical
Q3, Q4, Q5, Q6, Q7, Q8, Q9, Q10, Q11, Q12, Q13: FZT857TA; SOT-223-3_TabPin2
R17, R18, R19, R20, R21, R22, R29, R30, R31, R32, R33: 2.2k; R_0805_2012Metric_Pad1.20x1.40mm_HandSolder
R23, R24, R25, R26, R27, R28, R34, R35, R36, R37, R38: 180; R_0805_2012Metric_Pad1.20x1.40mm_HandSolder

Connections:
150V: J4.1; also elsewhere on the board
/PWM_0: R17.2; also elsewhere on the board
/PWM_1: R18.2; also elsewhere on the board
/PWM_2: R19.2; also elsewhere on the board
/PWM_3: R20.2; also elsewhere on the board
/PWM_4: R21.2; also elsewhere on the board
/PWM_5: R22.2; also elsewhere on the board
/PWM_6: R29.2; also elsewhere on the board
/PWM_7: R30.2; also elsewhere on the board
/PWM_8: R31.2; also elsewhere on the board
/PWM_9: R32.2; also elsewhere on the board
/PWM_10: R33.2; also elsewhere on the board
GND: C26.2, C27.2, C28.2, C29.2, C30.2, C31.2, C32.2, C33.2, C34.2, C35.2, C36.2, R23.2, R24.2, R25.2, R26.2, R27.2, R28.2, R34.2, R35.2, R36.2, R37.2, R38.2; also elsewhere on the board
unnamed: C26.1, Q3.1 (B), R17.1
unnamed: C27.1, Q4.1 (B), R18.1
unnamed: C28.1, Q5.1 (B), R19.1
unnamed: C29.1, Q6.1 (B), R20.1
unnamed: C30.1, Q7.1 (B), R21.1
unnamed: C31.1, Q8.1 (B), R22.1
unnamed: C32.1, Q9.1 (B), R29.1
unnamed: C33.1, Q10.1 (B), R30.1
unnamed: C34.1, Q11.1 (B), R31.1
unnamed: C35.1, Q12.1 (B), R32.1
unnamed: C36.1, Q13.1 (B), R33.1
unnamed: J4.2, Q3.2 (C)
unnamed: J4.3, Q4.2 (C)
unnamed: J4.4, Q5.2 (C)
unnamed: J4.5, Q6.2 (C)
unnamed: J4.6, Q7.2 (C)
unnamed: J4.7, Q8.2 (C)
unnamed: J4.8, Q9.2 (C)
unnamed: J4.9, Q10.2 (C)
unnamed: J4.10, Q11.2 (C)
unnamed: J4.11, Q12.2 (C)
unnamed: J4.12, Q13.2 (C)
unnamed: Q3.3 (E), R23.1
unnamed: Q4.3 (E), R24.1
unnamed: Q5.3 (E), R25.1
unnamed: Q6.3 (E), R26.1
unnamed: Q7.3 (E), R27.1
unnamed: Q8.3 (E), R28.1
unnamed: Q9.3 (E), R34.1
unnamed: Q10.3 (E), R35.1
unnamed: Q11.3 (E), R36.1
unnamed: Q12.3 (E), R37.1
unnamed: Q13.3 (E), R38.1

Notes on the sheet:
re value tbd 180 gives extra headroom, max current can be changed in software
10khz pwm w/ 2.2k, 4.7uF gives abt 25ms response from 0->50 duty
use tlv6001 op amp for pwm conv if the 10mV simulated frop is too high
FCS-12-SG and BHR-12-VUA
63911215521CAB

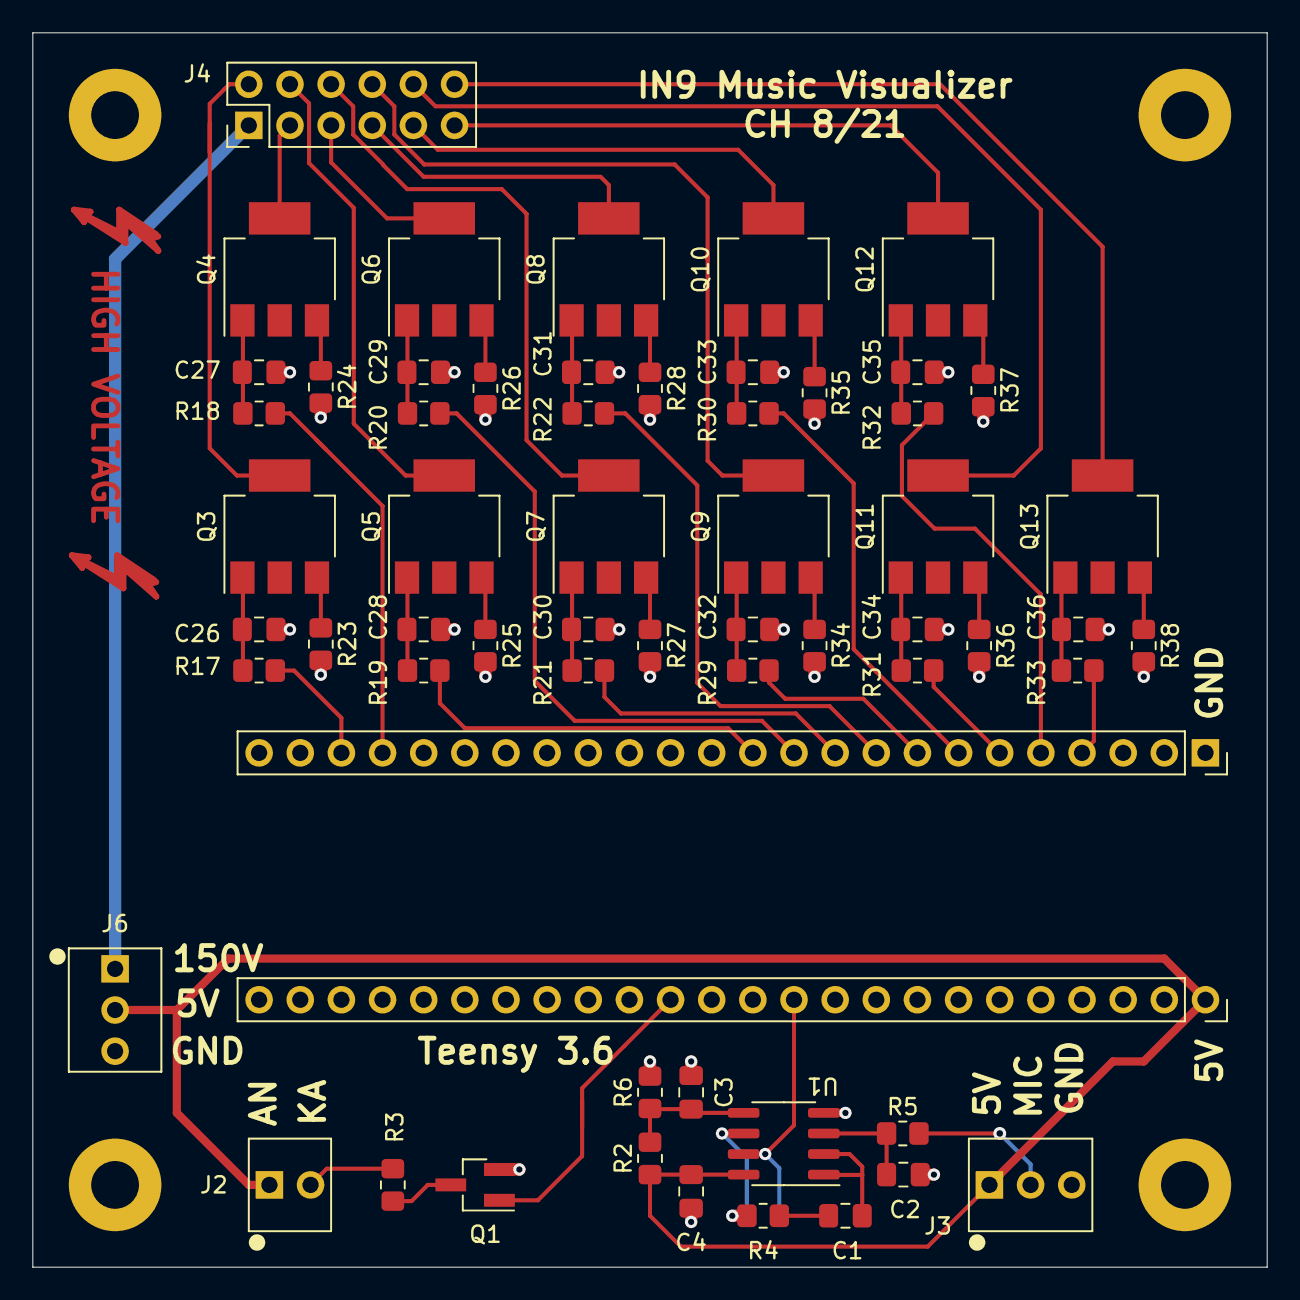
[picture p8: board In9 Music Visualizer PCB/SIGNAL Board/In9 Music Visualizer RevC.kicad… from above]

Board: 2 copper layers, 76.2 x 76.2 mm, 61 parts (1 on the bottom side), 57 nets.

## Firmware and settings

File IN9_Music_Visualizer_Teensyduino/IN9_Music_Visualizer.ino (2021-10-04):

#include <Audio.h>
#include <Wire.h>
#include <SPI.h>
#include <SD.h>
#include <SerialFlash.h>
#include <math.h>

int min_output = 25;
int max_output = 230; //maxiumum 0-255 PWM output for tubes, a tweakable value
//float exp_scalar = log(max_output); // exp scalar calculated from max_output. the maximum input to the exponential scaling function is expected to be 2.0f. saturation of max_output will be dealt with.

int increment = 4;
int decrement = 1;

typedef struct { // each channel is a frequency band, with one output tube, and other scalars for a pleasing visualization.
  int pin; // output pin
  int freq; // output pin freq
  int n_lo; // lower bound of FFT data
  int n_hi; // higher bound of FFT data
  float scale; // adjustable scale for more "sensitive" or noisy bands, default 1
  float level[4]; // an FIFO array of the past 16 values. The FFT is already oversampled, but this will help
  int out; // the output value, 0-255.

  void ch_init() {
    analogWriteFrequency(pin, freq);
  }

  void ch_write() {
    analogWrite(pin, out);
  }

  void ch_decrement() {
    out--;
    if (out < min_output) out = min_output;
    analogWrite(pin, out);
  }

  void ch_update(AudioAnalyzeFFT1024 fft1024) {
    int tmp_out = fft1024.read(n_lo, n_hi) * scale * 1024;

    if (tmp_out > max_output) tmp_out = max_output;
    if (tmp_out < min_output) tmp_out = min_output;

    if (tmp_out < out) {
      if (out >= 150) {
        out = out - decrement * 2;
      }
      else {
        out = out - decrement;
      }
    }
    if (tmp_out > out) {
      if (out >= 150) {
        out = out + increment / 4;
      }
      else {
        out = out + increment;
      }
    }
    if (tmp_out = out) out = tmp_out;
  }
} ch;

ch channel[11] = {
  {30,  1000,   0,    2,    0.8,    0,    0}, //C0 to F2
  {29,  1000,   3,    4,    0.8,    0,    0}, //F2 to F3
  {10,  1000,   5,    6,    1,    0,    0}, //F3 to C4
  {9,   1000,   6,    8,    1,    0,    0}, //C4 to C4
  {8,   1000,   8,    10,   1,    0,    0}, //C4 to F4
  {7,   1000,   9,   12,   1,    0,    0},  // F4 to A4
  {6,   1000,   12,   18,   1,    0,    0}, // A4 to C5
  {5,   1000,   18,   24,   1,    0,    0},  // C5 to G5
  {4,   1000,   24,   48,   1,    0,    0}, //G5 to C6
  {3,   1000,   48,   96,  1,    0,    0}, //C6 to C7
  {2,   1000,   96,  192,  0.8,    0,    0} //C7 and >
};

ch *pt;

// GUItool: begin automatically generated code
AudioInputAnalog         adc1;
AudioAnalyzePeak         peak1;
AudioAnalyzeFFT1024      fft;
AudioConnection          patchCord1(adc1, fft);
AudioConnection          patchCord2(adc1, peak1);
// GUItool: end automatically generated code

void setup() {
  
  for (int i = 0; i < 11; i++) {
    pt = &channel[i];
    pt->ch_init();
  }
  pinMode(13, OUTPUT);
  digitalWrite(13, HIGH);

  AudioMemory(12);
  fft.windowFunction(AudioWindowHanning1024);
  
  Serial.begin(9600);
  Serial.println("Setup Complete!");
}

void loop() {

  if (fft.available()) {
    if (peak1.read() > 0.1) {
      for (int i = 0; i < 11; i++) {
        pt = &channel[i];
        pt->ch_update(fft);
        pt->ch_write();
      }
    }
    else {
      for (int i = 0; i < 11; i++) {
        pt = &channel[i];
        pt->ch_decrement();
      }
    }
  }
  digitalWrite(13, !digitalRead(13));
  delay(7);
}
